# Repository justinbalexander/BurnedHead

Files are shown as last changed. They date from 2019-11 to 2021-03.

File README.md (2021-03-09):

# BurnedHead

A handheld, portable video game system designed with Kicad and programmed in C.

# Description

The processor is the STM32F767ZG, a Cortex-M7 processor selected for the ample
size of the instruction and data caches.  Currently at the board bring-up stage,
the functionality includes an RGB parallel interface, an MMC card socket, a 32MB
SDRAM clocked at 108MHz, D-pad, 4 front facing buttons, 2 shoulder buttons, 2
joysticks, and a speaker. The device is powered through a Micro-USB connector or
a rechargeable LiPo battery for portability.

The final product will load user-selectable ELF files off of the MMC compatible
card into the external RAM and run them as a process.

The project originally began in Zig but is transitioning to C to reduce
friction when integrating with libraries and vendor code and to allow progress
without requiring fiddling with a language still in beta.

# Building

## Cloning the Repository

This repository uses submodules to manage dependencies.

```bash
git clone --recurse-submodules https://github.com/vegecode/BurnedHead.git
```

## Building the Application

BurnedHead uses Makefiles.
Navigate to the base directory of the clone, and
point to the specific Makefile you want to build (currently only one):

Example:

```bash
make -f configurations/${CONFIGURATION_NAME}/Makefile
```

The resulting executable(s) are in `./build/${CONFIGURATION_NAME}`

# Debugging on the Target

Debugging is done using GDB in a shell with the JLink GDBServer providing the
connection to the remote target.

Running the shell script `./debug/start_debug /path/to/elf_file` will start the
GDBServer and connect GDB to it, then a gdb script loads the executable and sets
a temporary breakpoint at the reset handler.

A sample of some external RAM tests during board bring-up in a Vim/GDB session:
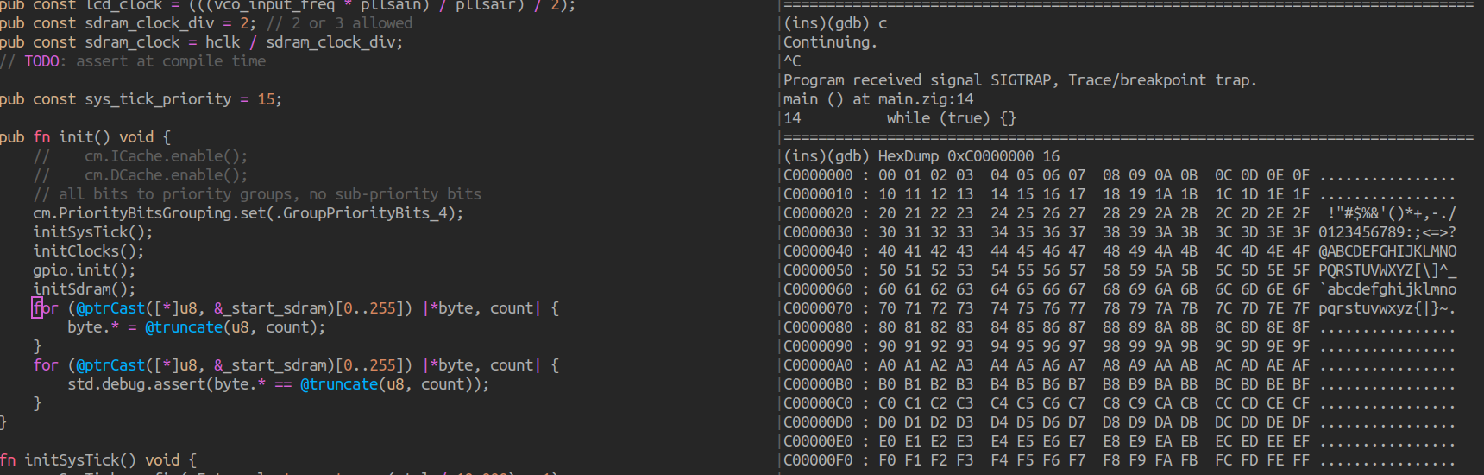
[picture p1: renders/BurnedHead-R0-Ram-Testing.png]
ram testing


Another easy alternative if you are using a JLink debug probe is to use Ozone,
the standalone debugger from Segger or Segger Embedded Workbench which are
both free to use for non-commercial purposes.

Integrating with Eclipse should also be possible using the MCU GNU Eclipse
plugins.

# Hand-Assembled Revision 0 Board

The back of the first revision of the board was assembled using solder paste and
a cast-iron skillet over a stand-alone burner for reflow. Some rework was
required as applying the paste without a stencil resulted in uneven application.
The front side components were hand soldered.

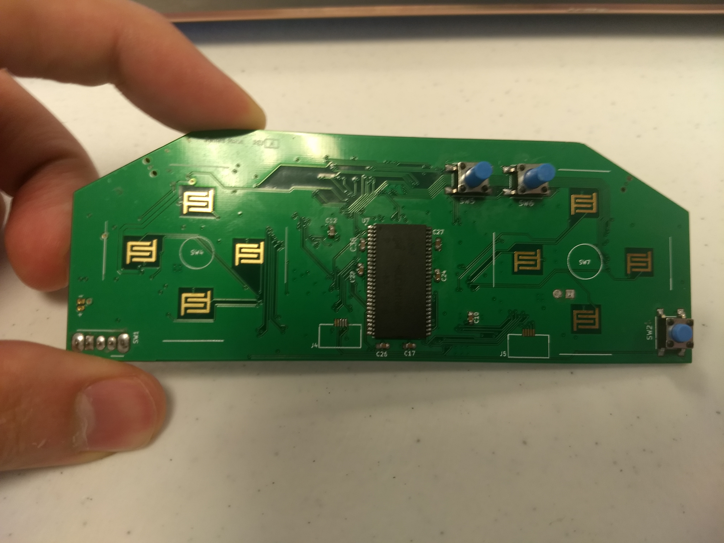
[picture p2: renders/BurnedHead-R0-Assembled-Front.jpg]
assembled front


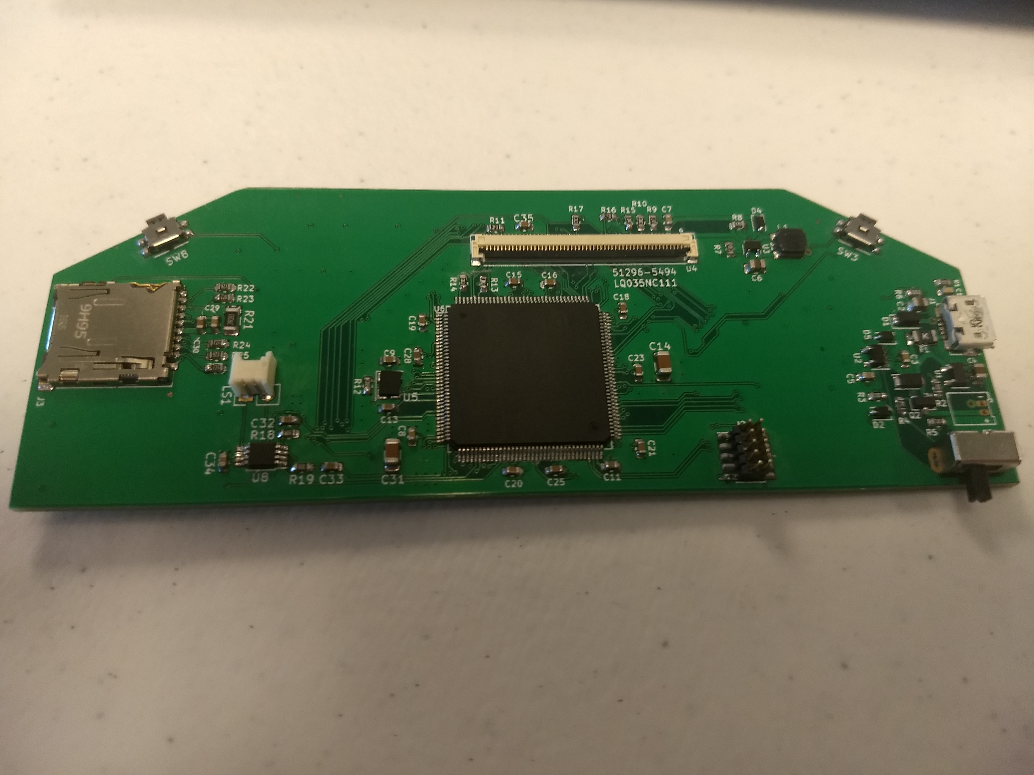
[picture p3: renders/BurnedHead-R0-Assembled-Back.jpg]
assembled back


# Renders

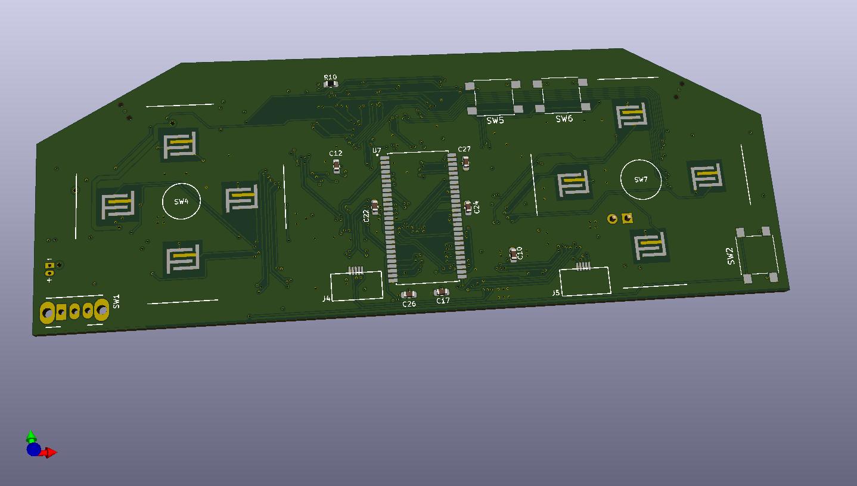
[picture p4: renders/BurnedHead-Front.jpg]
render


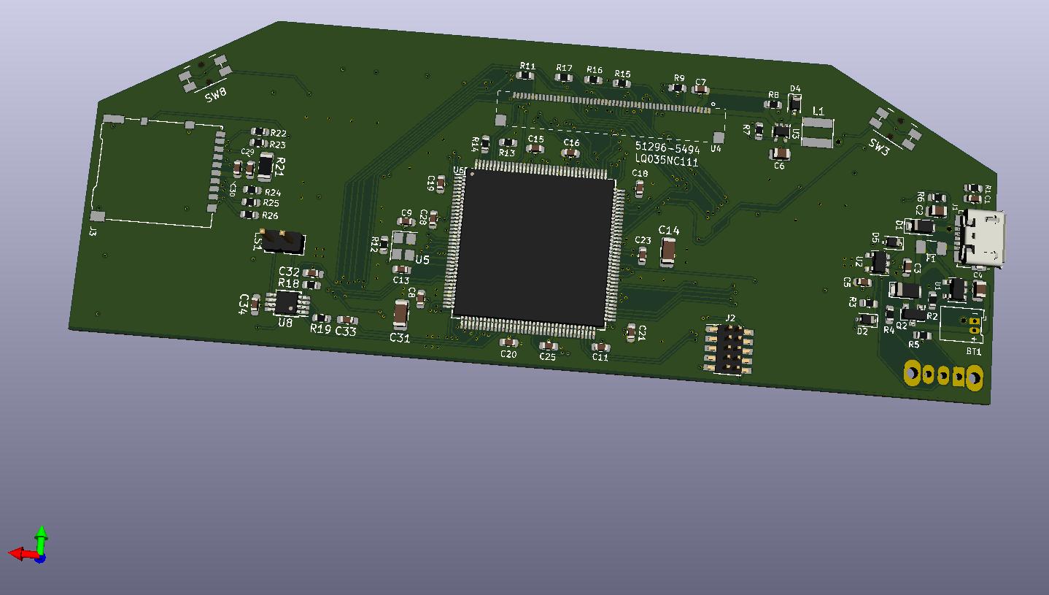
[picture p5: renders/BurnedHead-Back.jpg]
render


# Attributions

Some symbols and footprints  came from www.snapeda.com. See the library folder for the required
license and attributions.

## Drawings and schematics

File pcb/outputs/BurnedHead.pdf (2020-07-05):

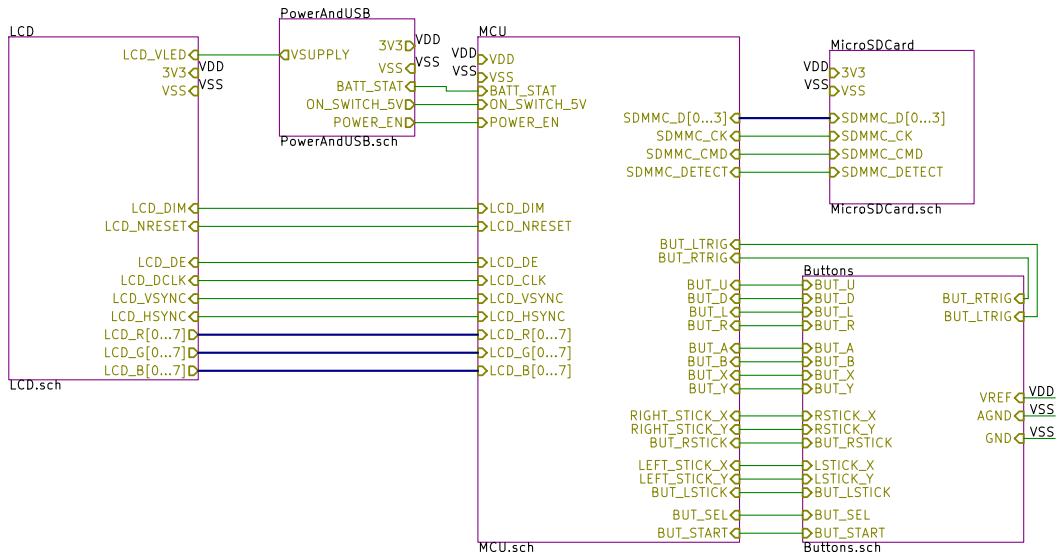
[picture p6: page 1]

File: BurnedHead.sch Sheet: / Justin Alexander

Id: 1/6 Title: Burned Head

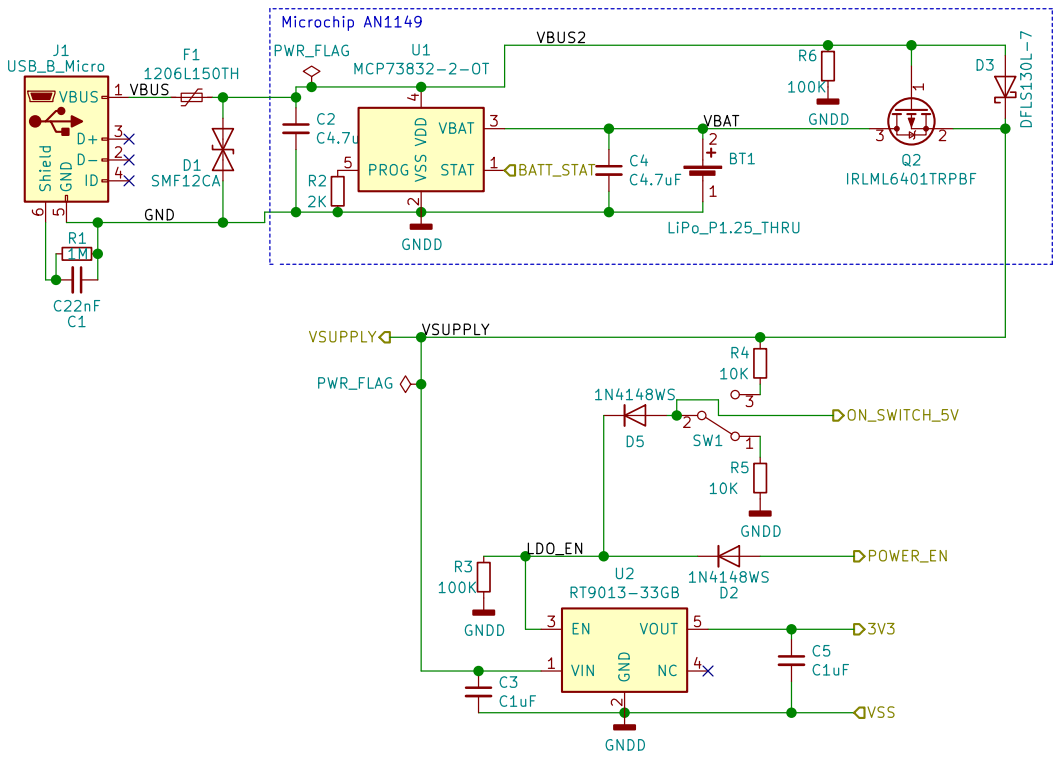
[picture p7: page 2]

File: PowerAndUSB.sch Sheet: /PowerAndUSB/ Justin Alexander

Id: 2/6 Title: Power and USB

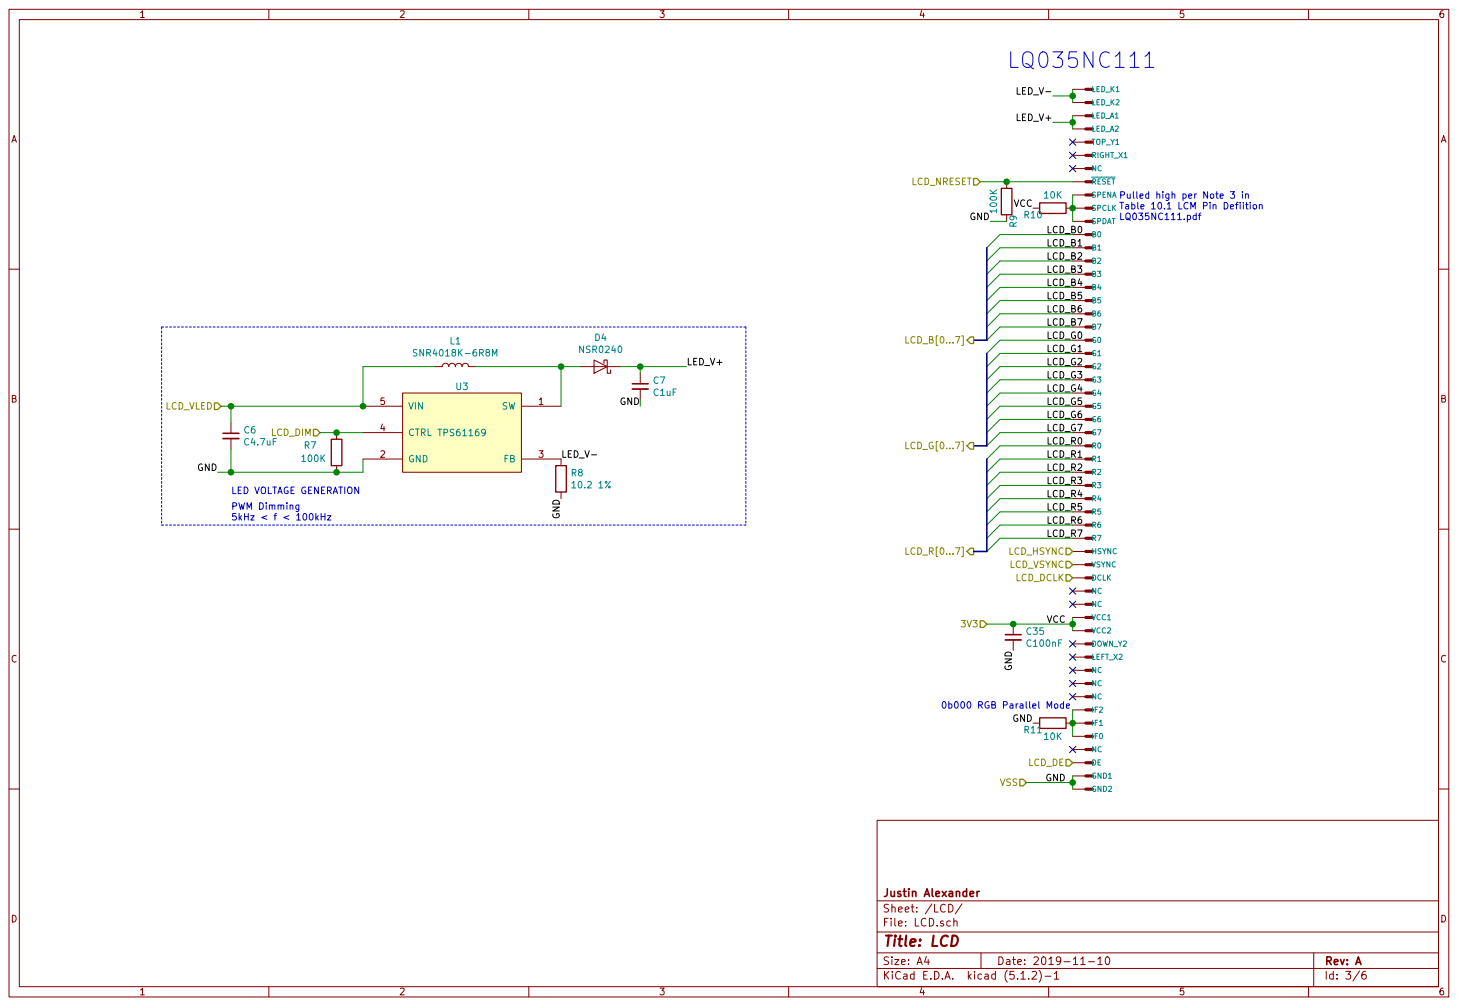
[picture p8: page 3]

Pulled high per Note 3 in Table 10.1 LCM Pin Defiition
SPDAT B0B1B2B3B4B5B6B7

File: LCD.sch Sheet: /LCD/ Justin Alexander

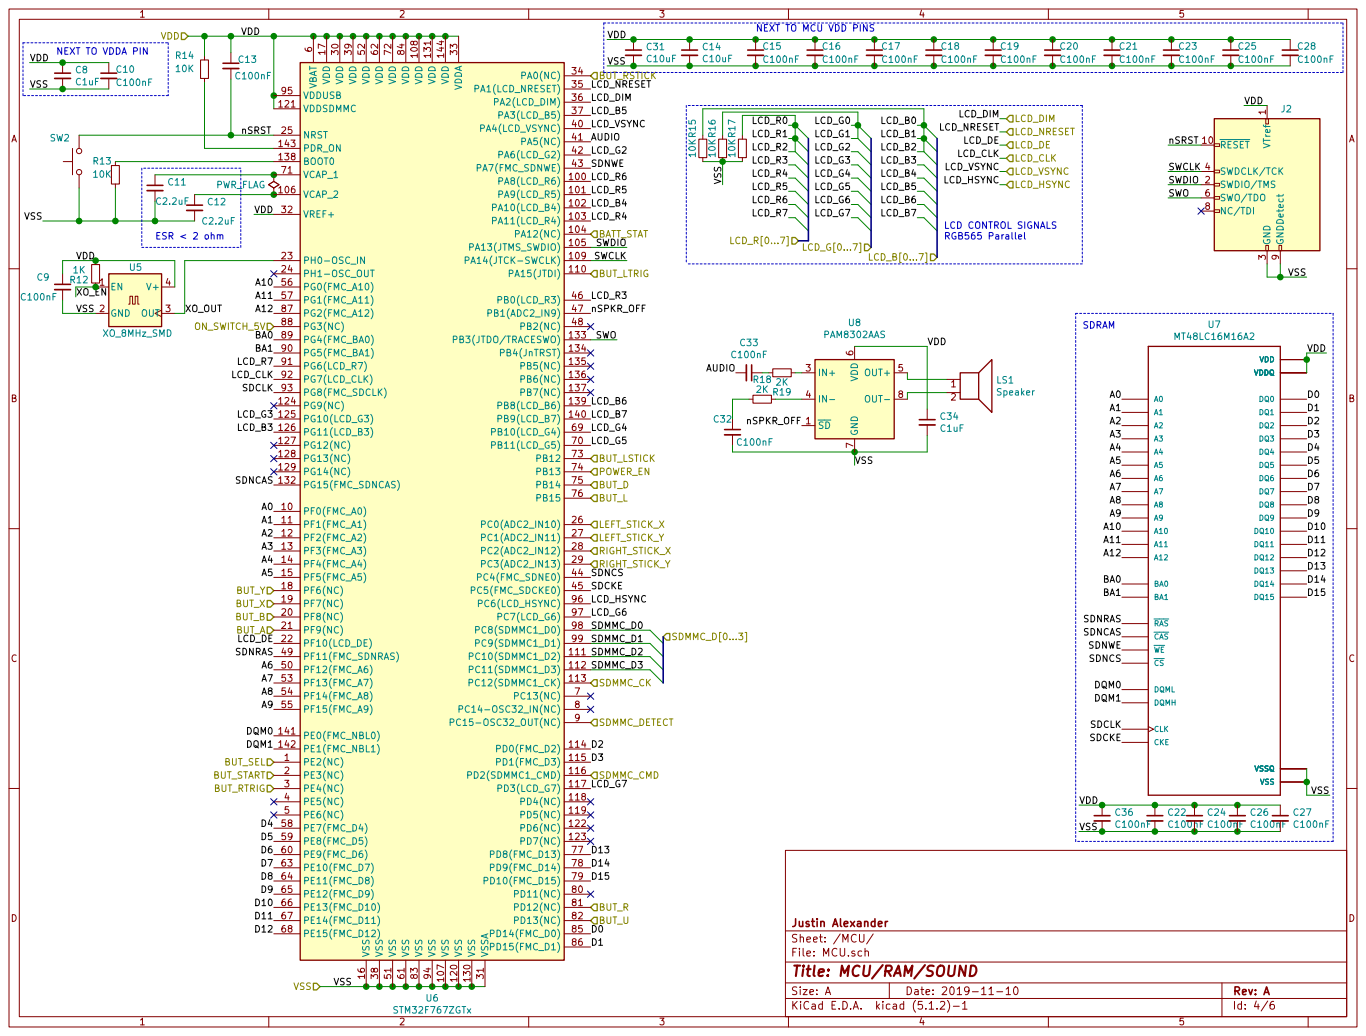
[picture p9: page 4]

VSS NEXT TO VDDA PIN

3 SWDCLK/TCK 4 SWO/TDO 6 NC/TDI 8 GNDDetect 9 J2VSS

File: MCU.sch Sheet: /MCU/ Justin Alexander

Id: 4/6 Title: MCU/RAM/SOUND

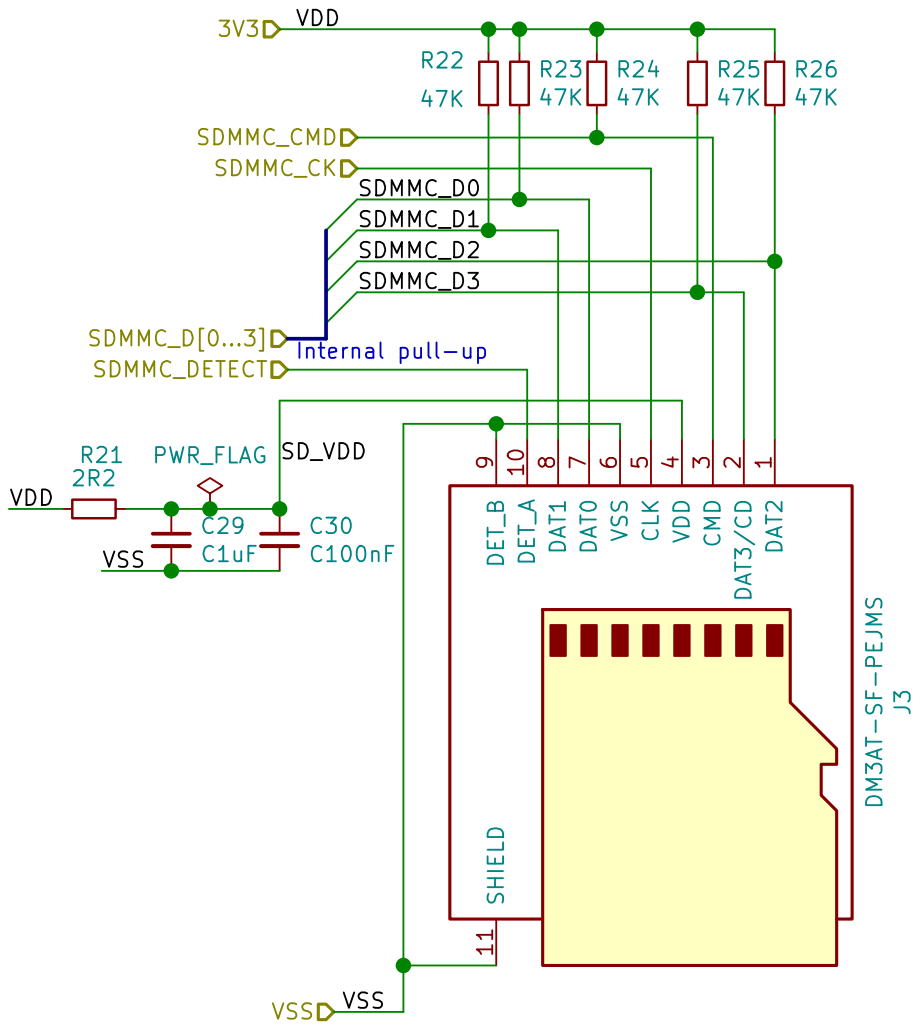
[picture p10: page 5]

3V3 VSS
File: MicroSDCard.sch Sheet: /MicroSDCard/ Justin Alexander DAT2

Id: 5/6 Title: Micro SD

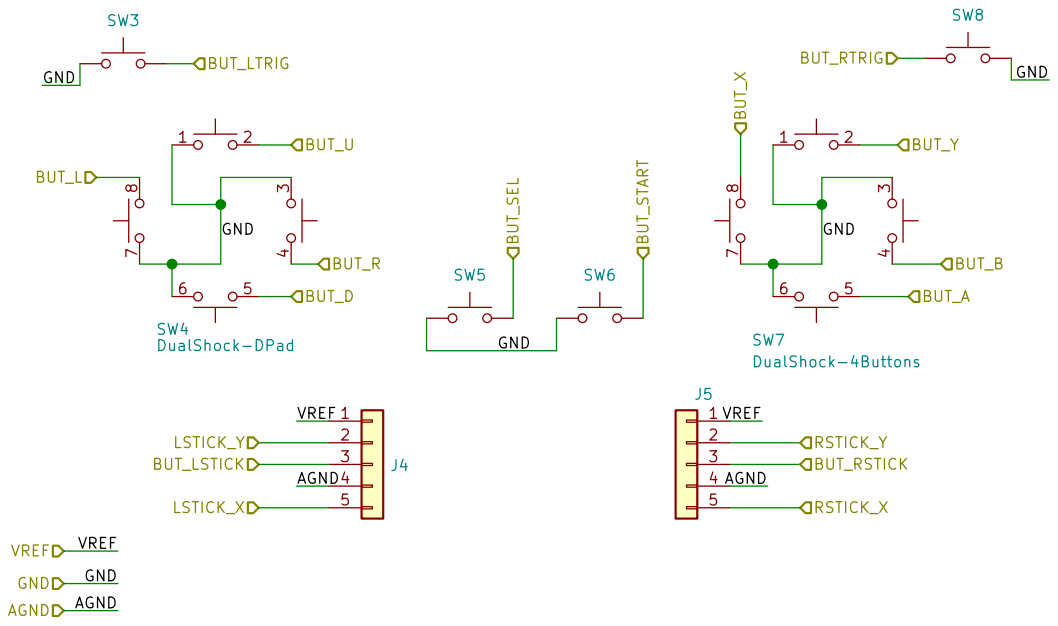
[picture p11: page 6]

File: Buttons.sch Sheet: /Buttons/ Justin Alexander

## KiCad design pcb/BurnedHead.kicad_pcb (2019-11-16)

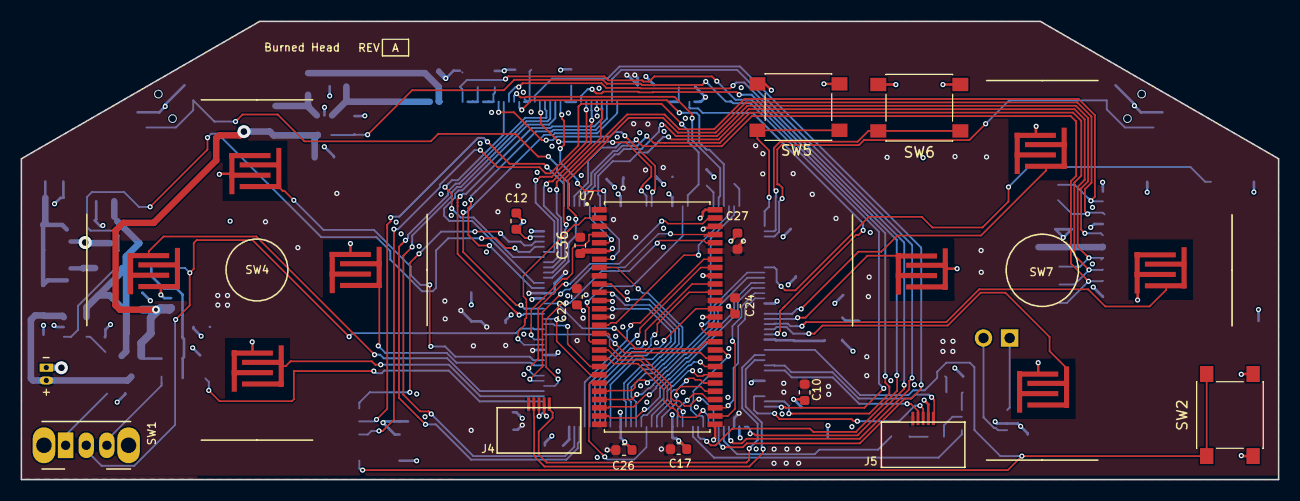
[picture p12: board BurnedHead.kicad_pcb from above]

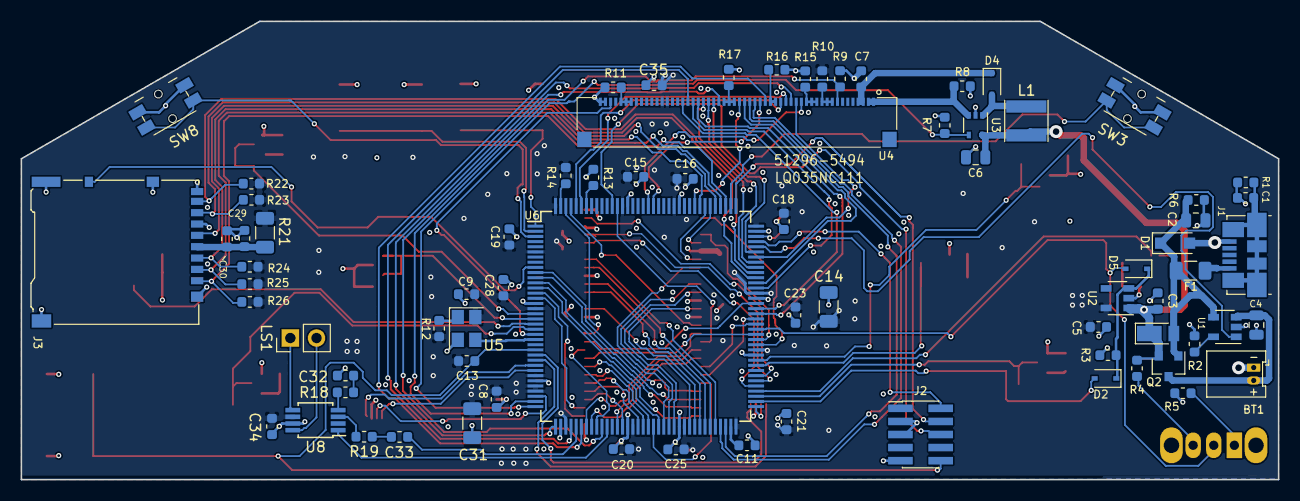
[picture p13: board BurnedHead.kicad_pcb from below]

Board: 4 copper layers, 121.9 x 44.4 mm, 92 parts (75 on the bottom side), 127 nets.

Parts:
BT1: LiPo_P1.25_THRU; Molex_PicoBlade_53048-0410_1x02_P1.25mm_Horizontal
C1: C22nF; C_0603_1608Metric
C2, C4, C6: C4.7uF; C_0805_2012Metric
C3, C5, C7, C8, C29, C34: C1uF; C_0603_1608Metric
C9, C10, C13, C15, C16, C17, C18, C19, C20, C21, C22, C23, C24, C25, C26, C27, C28, C30, C32, C33, C35, C36: C100nF; C_0603_1608Metric
C11, C12: C2.2uF; C_0603_1608Metric
C14, C31: C10uF; C_1206_3216Metric
D1: SMF12CA; D_SOD-123F
D2, D5: 1N4148WS; D_SOD-323
D3: DFLS130L-7; D_PowerDI-123
D4: NSR0240; D_SOD-323
F1: 1206L150TH; Fuse_1206_3216Metric
J1: USB_B_Micro; USB_Micro-B_Molex_47346-0001
J2: Conn_ARM_JTAG_SWD_10; PinHeader_2x05_P1.27mm_Vertical_SMD
J3: DM3AT-SF-PEJMS; microSD_HC_Hirose_DM3AT-SF-PEJM5
J4, J5: FPC_1x5_TopContact_P=0.5mm; XKB-Enterprise_X05B20U05T_1x05_P0.50mm_Horizontal
L1: SNR4018K-6R8M; L_Taiyo-Yuden_NR-40xx
LS1: Speaker; PinHeader_1x02_P2.54mm_Vertical
Q2: IRLML6401TRPBF; SOT-23
R1: 1M; R_0603_1608Metric
R2, R18, R19: 2K; R_0603_1608Metric
R3, R6, R7, R9: 100K; R_0603_1608Metric
R4, R5, R10, R11, R13, R14, R15, R16, R17: 10K; R_0603_1608Metric
R8: 10.2 1%; R_0603_1608Metric
R12: 1K; R_0603_1608Metric
R21: 2R2; R_1206_3216Metric
R22, R23, R24, R25, R26: 47K; R_0603_1608Metric
SW1: SW_SPDT; SW_CuK_OS102011MA1QN1_SPDT_Angled
SW2, SW5, SW6: SW_Push; SW_SPST_PTS645
SW3, SW8: SW_Push; Panasonic_EVQPUL_EVQPUC
SW4: DualShock-DPad; PS4-DualShock-CarbonPad-DPad
SW7: DualShock-4Buttons; PS4-DualShock-CarbonPad-4Buttons
U1: MCP73832-2-OT; SOT-23-5
U2: RT9013-33GB; SOT-23-5
U3: TPS61169; SOT-353_SC-70-5
U4: 51296-5494; 51296
U5: XO_8MHz_SMD; Crystal_SMD_3225-4Pin_3.2x2.5mm
U6: STM32F767ZGTx; LQFP-144_20x20mm_P0.5mm
U7: MT48LC16M16A2; MT48LC16M16A2TG-6A_IT
U8: PAM8302AAS; MSOP-8_3x3mm_P0.65mm

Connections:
/Buttons/BUT_A: SW7.5, U6.21
/Buttons/BUT_B: SW7.4, U6.20
/Buttons/BUT_D: SW4.5, U6.75
/Buttons/BUT_L: SW4.8, U6.76
/Buttons/BUT_LSTICK: J4.3, U6.73
/Buttons/BUT_LTRIG: SW3.2, U6.110
/Buttons/BUT_R: SW4.4, U6.81
/Buttons/BUT_RSTICK: J5.3, U6.34
/Buttons/BUT_RTRIG: SW8.2, U6.3
/Buttons/BUT_SEL: SW5.2, U6.1
/Buttons/BUT_START: SW6.2, U6.2
/Buttons/BUT_U: SW4.2, U6.82
/Buttons/BUT_X: SW7.8, U6.19
/Buttons/BUT_Y: SW7.2, U6.18
/LCD/LCD_B0: R15.2, U4.12, U4.13, U4.14
/LCD/LCD_B3: U4.15, U6.126
/LCD/LCD_B4: U4.16, U6.102
/LCD/LCD_B5: U4.17, U6.37
/LCD/LCD_B6: U4.18, U6.139
/LCD/LCD_B7: U4.19, U6.140
/LCD/LCD_DE: U4.52, U6.22
/LCD/LCD_DIM: R7.2, U3.4, U6.36
/LCD/LCD_G0: R16.2, U4.20, U4.21
/LCD/LCD_G2: U4.22, U6.42
/LCD/LCD_G3: U4.23, U6.125
/LCD/LCD_G4: U4.24, U6.69
/LCD/LCD_G5: U4.25, U6.70
/LCD/LCD_G6: U4.26, U6.97
/LCD/LCD_G7: U4.27, U6.117
/LCD/LCD_HSYNC: U4.36, U6.96
/LCD/LCD_NRESET: R9.1, U4.8, U6.35
/LCD/LCD_R0: R17.2, U4.28, U4.29, U4.30
/LCD/LCD_R3: U4.31, U6.46
/LCD/LCD_R4: U4.32, U6.103
/LCD/LCD_R5: U4.33, U6.101
/LCD/LCD_R6: U4.34, U6.100
/LCD/LCD_R7: U4.35, U6.91
/LCD/LCD_VLED: C3.1, C6.1, D3.1, L1.1, Q2.2, R4.1, U2.1, U3.5
/LCD/LCD_VSYNC: U4.37, U6.40
/LCD/LED_V+: C7.1, D4.1, U4.3, U4.4
/LCD/LED_V-: R8.1, U3.3, U4.1, U4.2
/MCU/A0: U6.10, U7.23
/MCU/A1: U6.11, U7.24
/MCU/A2: U6.12, U7.25
/MCU/A3: U6.13, U7.26
/MCU/A4: U6.14, U7.29
/MCU/A5: U6.15, U7.30
/MCU/A6: U6.50, U7.31
/MCU/A7: U6.53, U7.32
/MCU/A8: U6.54, U7.33
/MCU/A9: U6.55, U7.34
/MCU/A10: U6.56, U7.22
/MCU/A11: U6.57, U7.35
/MCU/A12: U6.87, U7.36
/MCU/AUDIO: C33.2, U6.41
/MCU/BA0: U6.89, U7.20
/MCU/BA1: U6.90, U7.21
/MCU/BATT_STAT: U1.1, U6.104
/MCU/D0: U6.85, U7.2
/MCU/D1: U6.86, U7.4
/MCU/D2: U6.114, U7.5
/MCU/D3: U6.115, U7.7
/MCU/D4: U6.58, U7.8
/MCU/D5: U6.59, U7.10
/MCU/D6: U6.60, U7.11
/MCU/D7: U6.63, U7.13
/MCU/D8: U6.64, U7.42
/MCU/D9: U6.65, U7.44
/MCU/D10: U6.66, U7.45
/MCU/D11: U6.67, U7.47
/MCU/D12: U6.68, U7.48
/MCU/D13: U6.77, U7.50
/MCU/D14: U6.78, U7.51
/MCU/D15: U6.79, U7.53
/MCU/DQM0: U6.141, U7.15
/MCU/DQM1: U6.142, U7.39
/MCU/LCD_CLK: U4.38, U6.92
/MCU/LEFT_STICK_X: J4.5, U6.26
/MCU/LEFT_STICK_Y: J4.2, U6.27
/MCU/ON_SWITCH_5V: D5.2, SW1.2, U6.88
/MCU/POWER_EN: D2.2, U6.74
/MCU/RIGHT_STICK_X: J5.5, U6.28
/MCU/RIGHT_STICK_Y: J5.2, U6.29
/MCU/SDCKE: U6.45, U7.37
/MCU/SDCLK: U6.93, U7.38
/MCU/SDMMC_CK: J3.5, U6.113
/MCU/SDMMC_CMD: J3.3, R24.2, U6.116
/MCU/SDMMC_D0: J3.7, R23.2, U6.98
/MCU/SDMMC_D1: J3.8, R22.2, U6.99
/MCU/SDMMC_D2: J3.1, R26.2, U6.111
/MCU/SDMMC_D3: J3.2, R25.2, U6.112
/MCU/SDMMC_DETECT: J3.10, U6.9
/MCU/SDNCAS: U6.132, U7.17
/MCU/SDNCS: U6.44, U7.19
/MCU/SDNRAS: U6.49, U7.18
/MCU/SDNWE: U6.43, U7.16
/MCU/SWCLK: J2.4, U6.109
/MCU/SWDIO: J2.2, U6.105
/MCU/SWO: J2.6, U6.133
/MCU/XO_EN: R12.1, U5.1
/MCU/XO_OUT: U5.3, U6.23
/MCU/nSPKR_OFF: U6.47, U8.1
/MCU/nSRST: C13.2, J2.10, SW2.2, U6.25
/MicroSDCard/SD_VDD: C29.1, C30.1, J3.4, R21.1
/PowerAndUSB/LDO_EN: D2.1, D5.1, R3.1, U2.3
/PowerAndUSB/VBAT: BT1.2, C4.1, Q2.3, U1.3
/PowerAndUSB/VBUS: F1.2, J1.1
/PowerAndUSB/VBUS2: C2.1, D1.1, D3.2, F1.1, Q2.1, R6.1, U1.4
/VDD: C5.1, C8.1, C9.1, C10.1, C13.1, C14.1, C15.1, C16.1, C17.1, C18.1, C19.1, C20.1, C21.1, C22.1, C23.1, C24.1, C25.1, C26.1, C27.1, C28.1, C31.1, C34.1, C35.1, C36.1, J2.1, J4.1, J5.1, R10.2, R12.2, R14.2, R21.2, R22.1, R23.1, R24.1, R25.1, R26.1, U2.5, U4.41, U4.42, U5.4, U6.6, U6.17, U6.30, U6.32, U6.33, U6.39, U6.52, U6.62, U6.72, U6.84, U6.95, U6.108, U6.121, U6.131, U6.144, U7.1, U7.3, U7.9, U7.14, U7.27, U7.43, U7.49, U8.6
GNDD: BT1.1, C1.1, C2.2, C3.2, C4.2, C5.2, C6.2, C7.2, C8.2, C9.2, C10.2, C11.2, C12.2, C14.2, C15.2, C16.2, C17.2, C18.2, C19.2, C20.2, C21.2, C22.2, C23.2, C24.2, C25.2, C26.2, C27.2, C28.2, C29.2, C30.2, C31.2, C32.2, C34.2, C35.2, C36.2, D1.2, J1.5, J2.3, J2.5, J2.9, J3.6, J3.9, J3.11, J4.4, J5.4, R1.1, R2.2, R3.2, R5.2, R6.2, R7.1, R8.2, R9.2, R11.2, R13.1, R15.1, R16.1, R17.1, SW2.1, SW3.1, SW4.1, SW4.3, SW4.6, SW4.7, SW5.1, SW6.1, SW7.1, SW7.3, SW7.6, SW7.7, SW8.1, U1.2, U2.2, U3.2, U4.53, U4.54, U5.2, U6.16, U6.31, U6.38, U6.51, U6.61, U6.83, U6.94, U6.107, U6.120, U6.130, U7.6, U7.12, U7.28, U7.41, U7.46, U7.52, U7.54, U8.7
unnamed: C1.2, J1.6, R1.2
unnamed: C11.1, U6.71
unnamed: C12.1, U6.106
unnamed: C32.1, R18.2
unnamed: C33.1, R19.1
unnamed: D4.2, L1.2, U3.1
unnamed: LS1.1, U8.5
unnamed: LS1.2, U8.8
unnamed: R2.1, U1.5
unnamed: R4.2, SW1.3
unnamed: R5.1, SW1.1
unnamed: R10.1, U4.9, U4.10, U4.11
unnamed: R11.1, U4.48, U4.49, U4.50
unnamed: R13.2, U6.138
unnamed: R14.1, U6.143
unnamed: R18.1, U8.4
unnamed: R19.2, U8.3

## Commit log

2019-11-11 Schematics, pcb, gerbers, drill files
    [BurnedHead.kicad_pcb, BurnedHead.sch, Buttons.sch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]
2019-11-11 Regenerate output files with newly renamed project files, add paste layers to Gerbers
    [BurnedHead-B_Cu.gbr, BurnedHead-B_Mask.gbr, BurnedHead-B_Paste.gbr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]
2019-11-16 Add capacitor to lcd vdd and one more to ram vdd pin, updating parts-lib
    [BurnedHead.kicad_pcb, BurnedHead.sch, Buttons.sch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]
2019-11-16 Remove accidental slots on ground plane from adjacent vias, add rev to silkscreen, re-generate gerbers
    [BurnedHead-B_Cu.gbr, BurnedHead-B_Mask.gbr, BurnedHead-B_Paste.gbr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]
2020-02-22 Correct memory map for STM32F767ZGT
2020-02-23 Break debug script into two scripts, init and start, to be run in separate shells
    backgrounded gdb server was still getting sigint when interrupting gdb and I couldn't figure out how to stop it
2020-02-27 Add basic CubeMX settings with all pin assignments verified
2020-06-18 Add pdf of schematic and bom, move gerbers and drill files to git lfs
    [BurnedHead-B_Cu.gbr, BurnedHead-B_Mask.gbr, BurnedHead-B_Paste.gbr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]
2020-06-18 Add all large files and kicad project files, schematics, etc. to git lfs
    [BurnedHead.sch, Buttons.sch, LCD.sch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]
2020-07-05 Hopefully remove git lfs
    [BurnedHead-B_Cu.gbr, BurnedHead-B_Mask.gbr, BurnedHead-B_Paste.gbr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]
2020-07-06 Add gpio pin get
2020-07-08 Add docs command to zig build, currently not very useful
2020-07-25 Initialize SDRAM, add monotonic timer
    Has issue where every 3rd and 4th byte don't write
2020-11-14 Build STM32 HAL and use to initialize hardware
2021-02-14 Move pcb files into subfolder
    [BurnedHead-B_Cu.gbr, BurnedHead-B_Mask.gbr, BurnedHead-B_Paste.gbr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]
2021-02-16 Add startup assembly file and Makefile
    Modifies linker script to provide expected symbols from startup file
2021-02-17 Disable sdmmc for now, requires card to be inserted
2021-02-18 Update to STM32CubeMX v6.1.1
